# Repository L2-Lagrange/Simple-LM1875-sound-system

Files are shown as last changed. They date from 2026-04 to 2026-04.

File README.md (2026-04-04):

# Simple-LM1875-sound-system
<br>
<p align="center"><strong>Introduction</strong></p>
Below is my design for a simple, modular LM1875 bridge-tied-load (BTL) sound system. It is a practical analog amplifier system that is easy to build, has great performance  and makes for a great analog system design learning project. <br>
<br>
This writeup is meant to offer practical advice for hobbiests and engineers trying to learn more about analog amplifier hardware, and who may be interested in building similar circuits. It is not meant to be an academic document but I do brush on some academic topics. I attempt to focus on the topics I think are important while being as brief as possible.<br>
<br>
The core system is the power amplifier board, but I also provided information on the receiver I used for this version of the build.<br>

<br>

<p align="center">
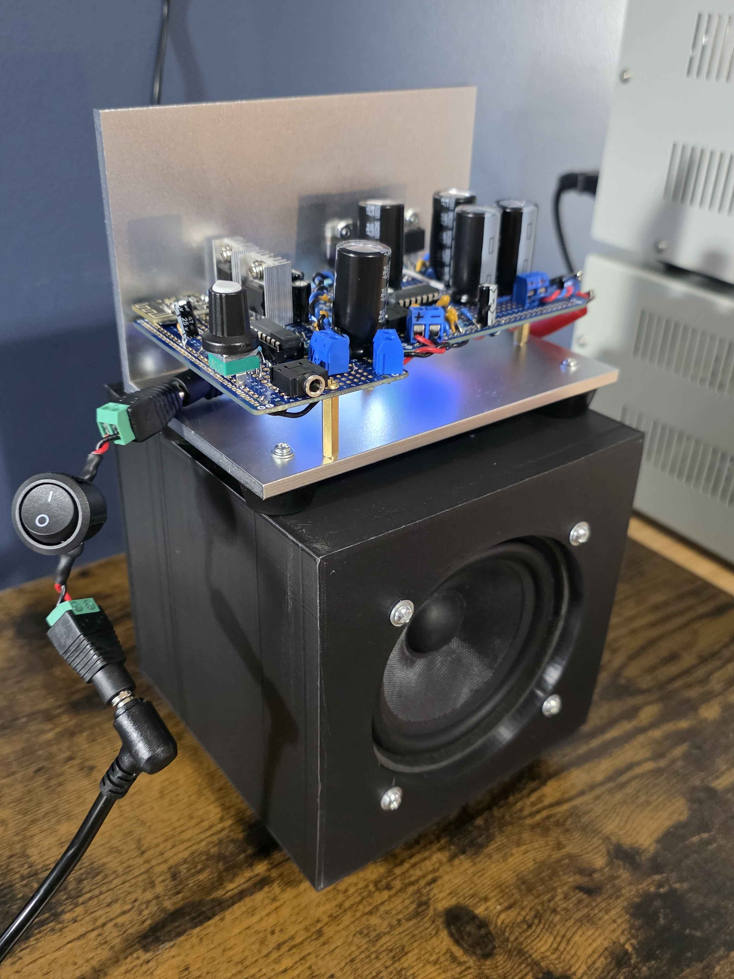
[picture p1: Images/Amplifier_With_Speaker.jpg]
  <br>
  <em>Amplifier system sitting on 3d printed speaker</em>
</p>

<br>
<br>

<p align="center"><strong>The Design:</strong></p>

The system will work with any standard audio signal source, it does not need to be a bluetooth receiver. In this case my signal source is a [$3 bluetooth receiver module from Amazon](https://www.amazon.com/hiBCTR-Wireless-Bluetooth-Audio-Receiver/dp/B0FDLGMMYC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), which is improved with an analog filter stage. You could also use the design as a guitar amplifier or something similar.

<p align="center">
  <br>
  <em> LM1875 amplifier system prototype </em>
</p>

This design is modular and consists of two main boards. One board is a receiver that includes an analog filter for reducing DAC noise, followed by a gain stage and output buffer. The other board is an LM1875 power amplifier board with an input buffer, phase splitter, and bridge-tied-load output. Each subsystem can be built one at a time on breadboard/perfboard and tested before building the next stage. They can also be used as building blocks for other systems.

<p align="center">
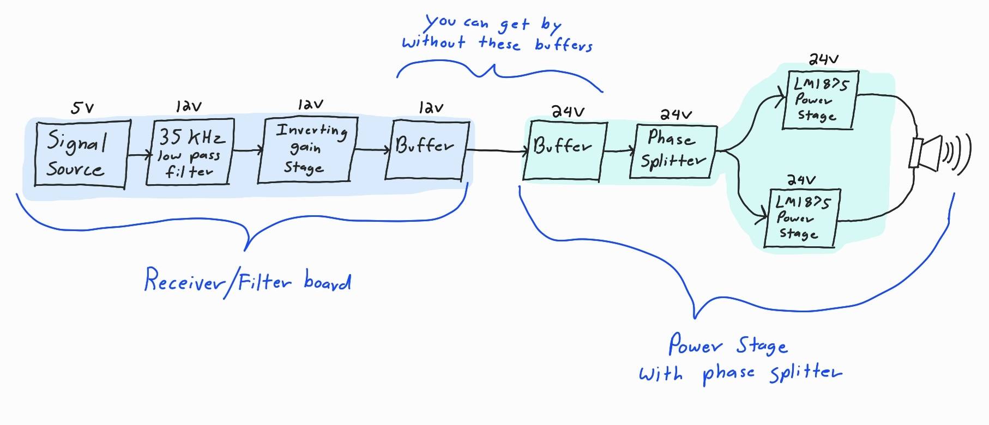
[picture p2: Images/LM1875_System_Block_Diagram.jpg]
  <br>
  <em>System block diagram</em>
</p>
<br>
<br>

<p align="center"><strong>Power Stage:</strong></p>

The LM1875 power stage has a BTL output. This means the output is taken across a pair of amplifiers that have opposite outputs which doubles the voltage. Doubling the voltage increases power output by roughly 4 times compared to a single non BTL LM1875 (schematic below) making it more practical to build loud analog amplifiers at low voltage rails.

<p align="center">
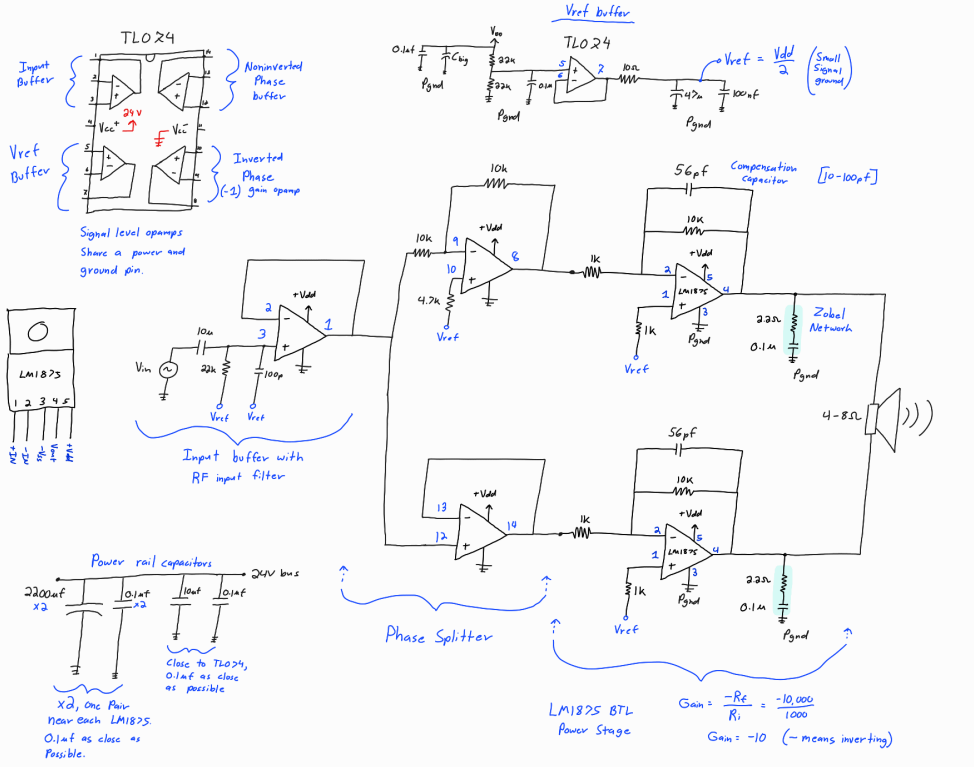
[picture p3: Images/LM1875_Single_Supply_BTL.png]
  <br>
  <em>Schematic:  Power Stage with phase splitter</em>
</p>

To make BTL work, we use a phase splitter. The phase splitter takes in one signal, and outputs the original signal as well as its inverted version. The phase splitter outputs drive the LM1875 power amplifier stage. This design runs from a single DC rail instead of positive and negative rails, so the phase splitter and power stage require a virtual ground. It uses a buffered voltage divider (Vref buffer) to generate and distribute the virtual ground to the TL074 and LM1875 amplifiers. The virtual ground at half the supply voltage is what allows us to run the system with a single +24V rail. 

The power stage is set up as a relatively standard inverting amplifier, but it is not an opamp. The datasheet for the LM1875 recommends designing it with gains of 10 or greater for stability purposes, so the power stage has 10 gain. The vast majority of amplifier chips cannot drive a speaker, which is why we are using the LM1875. The LM1875 is still avalible in standard supply chains.

The power stage includes compensation capacitors in the LM1875 feedback loops (56pf capacitors) as well as zobel network (2.2ohm + 0.1uf) on output. The LM1875 tends to oscillate without a zobel network so it is very important. The feedback capacitors improve square wave response, reducing ringing and indicating good stability. Without them there is noticable ringing on the rising and falling edges.

<p align="center">
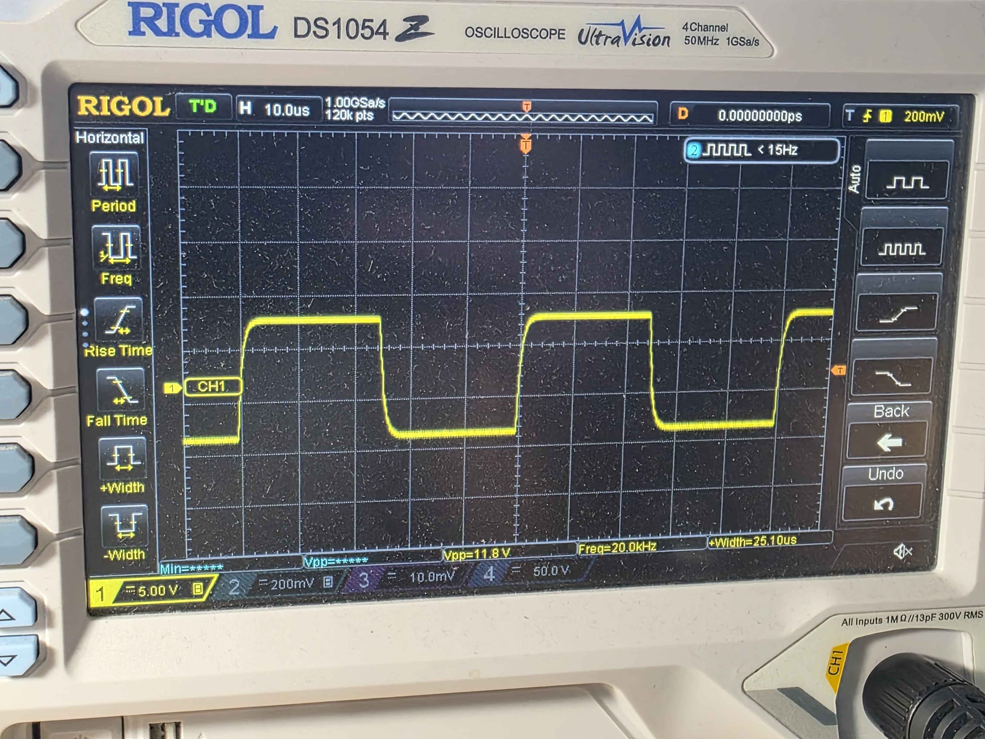
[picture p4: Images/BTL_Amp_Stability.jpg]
  <br>
  <em>Power stage tuned with 56pf capacitor with 8 ohm test load</em>
</p>

<br>
<br>
<p align="center"><strong>Receiver Board:</strong></p>

The receiver board also uses a buffered voltage divider, but its power setup is more complicated due to the addition of the LM7805 and LM7812 voltage regulators. The regulators are separated from the main power bus by a pi filter. This is helpful for cleaning up some noise from cheap wall power supplies. The 7812 regulator is there to power the 12V analog filter section, and the 7805 regulator is used to power the 5V receiver board. (Depending on opamp and receiver choice, this board could be made to run on a single 3.3V rail.)

<p align="center">
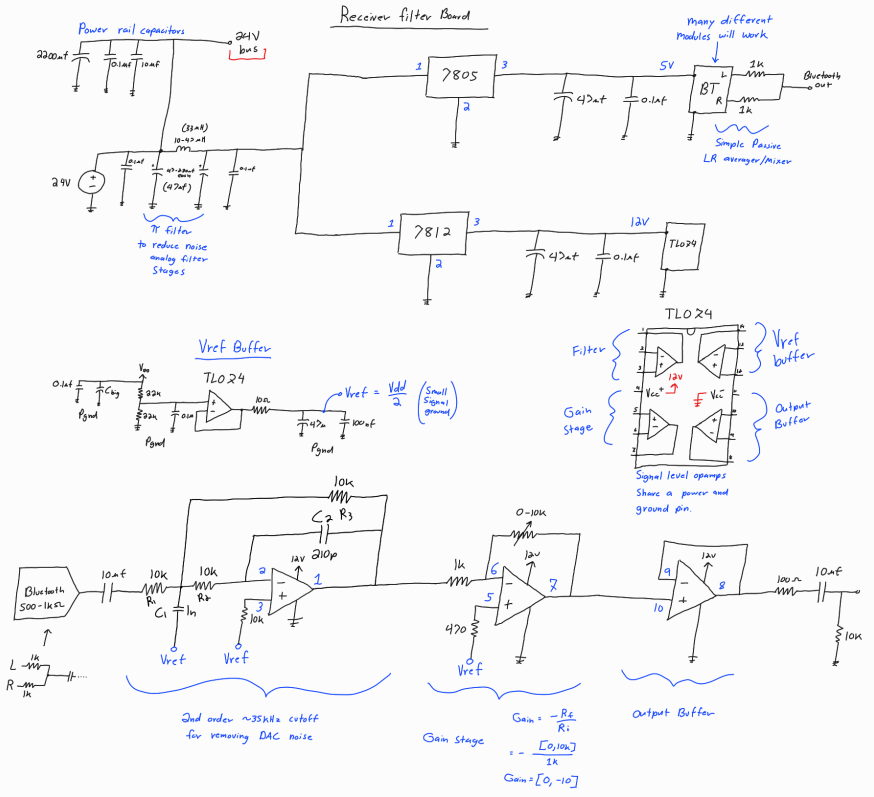
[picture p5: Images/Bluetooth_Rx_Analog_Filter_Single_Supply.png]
  <br>
  <em>Schematic:  Receiver/Filter board</em>
</p>

The most important feature of the receiver board is the 2nd order ~35khz cutoff filter. This is what allows us to use various bluetooth receivers, or arbitrary signal sources. The noise is technically higher than audible frequency, but its good design practice to get rid of it. The 2nd order filter topology originally came from a Texas Instruments design manual, but they have removed it from the internet. I redesigned it for 35khz and this version works well for audio.

<p align="center">
  
  <br>
 <em>Sine wave before (yellow) and after (blue) the 35khz filter</em>
</p>
 
The above images are an example of what the lowpass filter after a DAC accomplishes. The yellow signal is the output from the [bluetooth receiver](https://www.amazon.com/hiBCTR-Wireless-Bluetooth-Audio-Receiver/dp/B0FDLGMMYC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), and the blue signal is the output of the 35khz filter. The high frequency noise has been significantly removed, and the output is much cleaner. This sine wave is then reinverted by the gain stage (0-10 gain magnitude) and then finally sent to the output buffer. 

The signal then goes to the input stage of the power stage board, which is another buffer. These buffers are for modularity and stage separation, but they could be removed. After the buffer the signal is phase split to drive the BTL power stage.

<br>
<br>
<p align="center"><strong>Output Power Measurements:</strong></p>

The power stage measurements are taken 'single ended,' which means the measurement are taken from one amplifier output to ground as opposed to taking the output across the load. This is because the bridge-tied-load is floating with respect to ground. To interpret the measurements, you would double the voltage across the load (the output is differential). You could also measure both channels and add them using an oscilloscope math function. 

The power calculations get a little bit complicated due to the BTL changing 'how the amplifier sees the load.' This configuration makes each amplifier half bridge 'see' half the resistance of the load, so it 'sees' 4 ohms when connected to an 8 ohm load. 

<p align="center">
  
  <br>
 <em>Left: Test setup,    Right: Max power into 8 ohms before clipping</em>
</p>

The maximum output voltage before clipping is roughly 14.6V pk-pk per channel. This means the voltage across the load would be 29.2V pk-pk (10.36Vrms). At this point we can use (V^2)/R to estimate a power output of 13.42W before noticeable distortion. This is significantly louder than you would expect. It can operate into clipping and still sound good. The power output is similar into a 4 ohm load, but it has less voltage headroom before clipping and significantly higher current. 

<p align="center">
  
  <br>
 <em>Left: Onset of clipping with 8 ohm load,   Right: Clipping with 8 ohm load</em>
</p>

As the system approaches clipping, it gets a little bit of fuzz on top of the sine wave before flattening out with increasing input amplitude. When listening to music the bass tends to clip a tiny bit first and its not audible. 
<br>
<br>
<p align="center"><strong>LEDs:</strong></p>

I included three LEDs on the power rails. I would recommend adding at least one to each board. They indicate whether or not the circuit is on and the capacitors are charged. It also gives the capacitors a discharge path when the circuit is powered off. I chose to use a 3rd LED for visual reasons.

<p align="center">
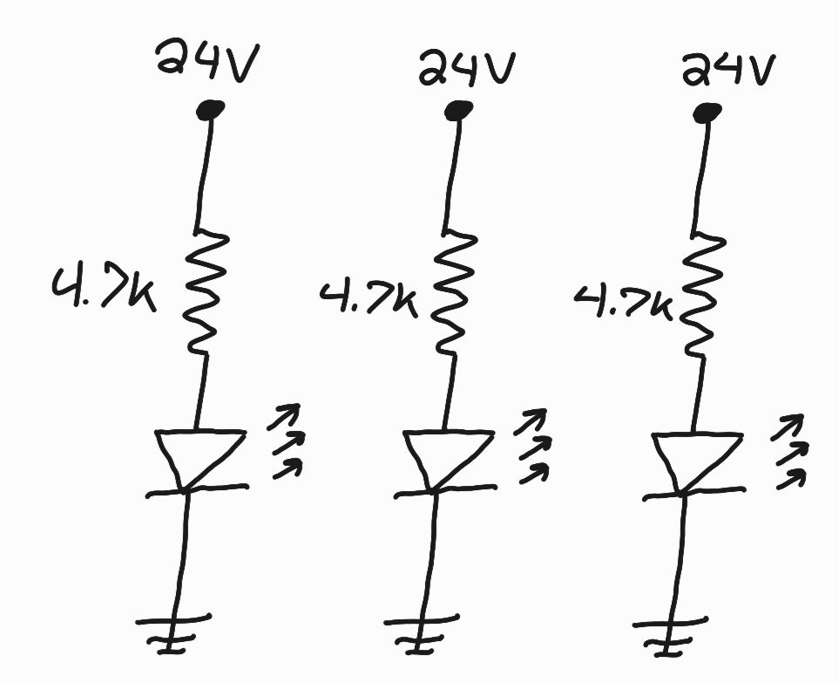
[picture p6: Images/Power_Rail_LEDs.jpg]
  
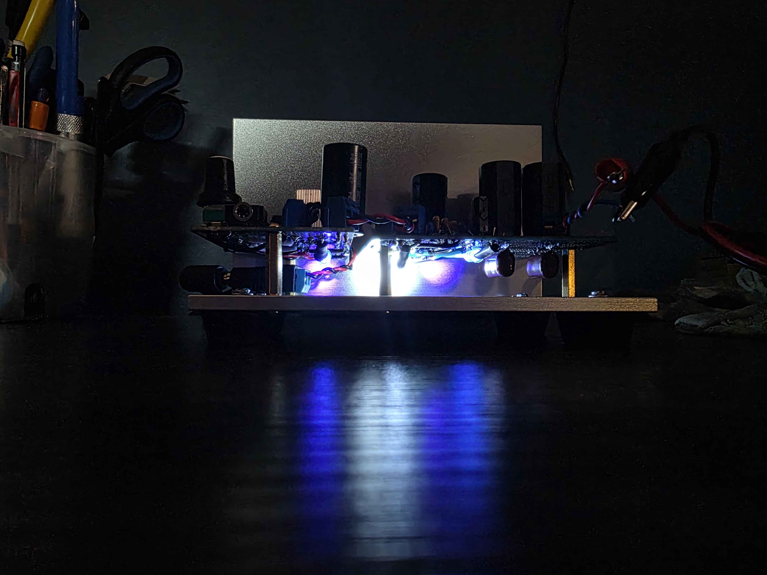
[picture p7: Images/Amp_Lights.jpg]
  <br>
 <em>Power rail LEDs</em>
</p>

<br>
<br>
<p align="center"><strong>Heat Sink:</strong></p>

Proper heat sinking is important for the power stage. For the heat sink I used an [aluminum L bar](https://www.amazon.com/OTTFF-Bracket-aluminum-Profile-Corner/dp/B0DD3BDWT6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) which gave me space to mount both boards on standoffs, but you can get by with [significantly smaller heat sinks](https://www.amazon.com/dp/B07B62V4FP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). You will not be able to test the system at full power with the smaller heat sinks, but it will get plenty loud. 

I placed my prototype on the aluminum L bar and used a sharpie to mark where I needed to drill. I used cheap drill bits appropriate for aluminum and added a little bit of vegetable oil to the drill hole (the vegetable oil makes a big difference). This worked very well. A small amount of thermal paste significantly improves the thermal transfer from the LM1875 chips to the heat sink.

<p align="center">
  
  <br>
 <em>Left: Power stage on heat sink ,   Right: Drilling the heat sink</em>
</p>

Once a heat sink is drilled the LM1875 chips can be connected to it. Make sure to plan your builds to include the heat sink from the start. It is very difficult to properly heat sink chips that are populated in the center of boards, and you do not want your system to be completely limited by heat sink performance.

<br>
<br>
<p align="center"><strong>LM1875 Single Supply Inverting Amplifier (not BTL):</strong></p>

When building this system for the first time it helps to build a simple version of the power stage. The design below is an LM1875 inverting power stage I designed. The output capacitor is very important in this design, but it should be removed for BTL.
<br>
<p align="center">
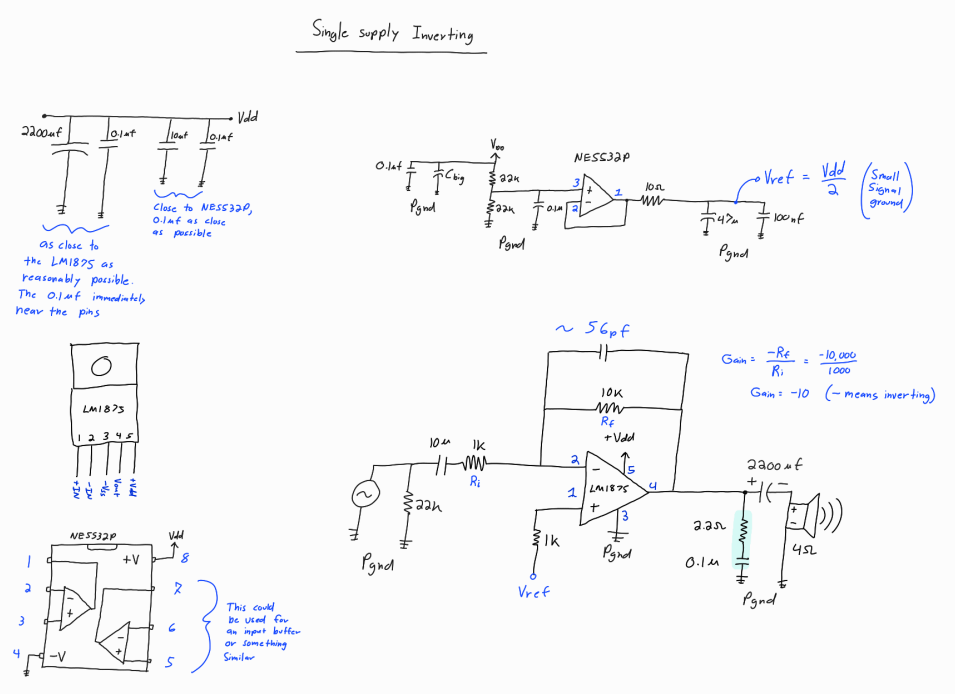
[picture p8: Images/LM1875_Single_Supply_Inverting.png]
  <br>
  <em>LM1875 non BTL inverting power amplifier</em>
</p>

This can easily be tuned on a breadboard. I've also built three soldered versions to use in my [LR4 active system](https://www.linkwitzlab.com/filters.htm) design. It has great performance on its own, but significantly better power performance as a BTL. The feedback capacitor can be tuned while measuring a 10khz square wave and looking at the edges. I tuned it by swapping out capacitor values and taking measurements. Below is an image of the properly tuned LM1875 power stage square wave. Notice the lack of ringing on the edges.

<p align="center">
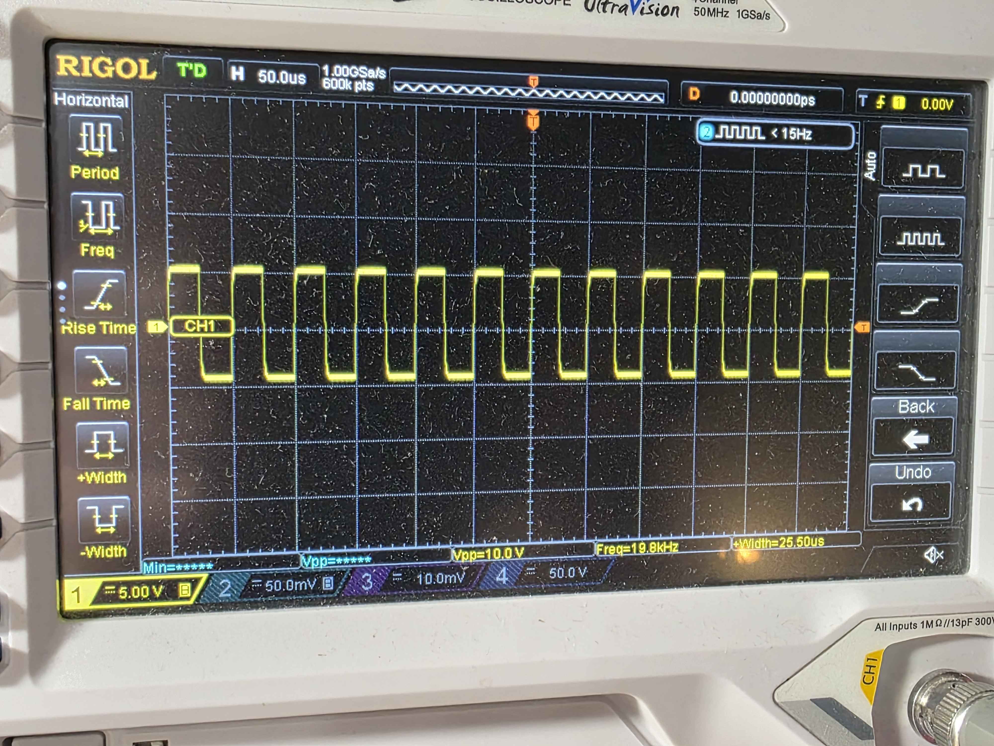
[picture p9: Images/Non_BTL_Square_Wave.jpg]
  <br>
  <em>Stable square wave resulting from proper compensation</em>
</p>

<br>
<br>
<p align="center"><strong>Conclusion:</strong></p>

The performance of the system is better than I expected, so I decided to explain how it works and provide advice for building something similar. The analog part of the reciever board and LM1875 BTL power board are both great building blocks for larger systems. That being said I have spent more time testing systems built from the non BTL inverting version and that is a great starting place. Almost every component could be swapped out for a similar component within specification. For example the TL074 and NE5532P circuits could use higher quality modern amplifiers, but that is not worth it unless you have a very high quality signal source. Even then the NE5532P is a perfectly fine hifi part. There is a lot of wiggle room in the design in general. Just make sure to check the voltage ratings on the components you choose so they will actually work in the design. 

The system is designed to work with a somewhat wide input supply voltage. One of the major advantages of using off the shelf power supplies is being able to take advantage of the built in protectoin circuitry. If you design your own power supply it is important to include sufficient protection circuitry. 

Below are various loosely related bits of information that didnt fit cleanly into a previous sections. It includes practical information from my eperience working with this design.

<br>

<br>
<br>
<p align="center"><strong>Build Notes:</strong></p>

1. The semiconductors and electrolytic capacitors for this project were ordered from Digikey. The LM1875 chips are the most important component to get from a reliable source. Do not buy them on Amazon. 

2. The system is powered by a single DC voltage source between 18-30V, and performs great with [cheap 24V wall power supply bricks](https://www.amazon.com/100V-240V-Terminal-Connector-Adapter-5-5x2-1mm/dp/B0CW598HV8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). This means you do not need to build a power supply to design a similar system. That being said a well designed 24V linear power supply using an LM317HV would be a good choice.

3. The speaker below the amplifier is 3D printed, but this system should work with any speaker rated at least 30W. This particular build uses a single [PRV Audio 4 inch midrange 30W RMS speaker](https://www.amazon.com/PRV-4MR60-4-Midrange-Woofer-Speaker/dp/B00RC3Z9H2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), but I have tested it with many other 4 and 8 ohm speakers. This document focuses on the power amplifier and bluetooth receiver boards.

4. The bluetooth receiver used in this particular build [costs roughly $3 on Amazon.](https://www.amazon.com/hiBCTR-Wireless-Bluetooth-Audio-Receiver/dp/B0FDLGMMYC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) This receiver works great and uses incredibly low power, but there are more hifi options. There are also no official datasheets available for the chip, but it is still easy to work with. The analog filter after the bluetooth receiver significantly improves the signal quality and makes it usable in a system like this.

5. The power rails include bulk electrolytic capacitors and small ceramic capacitors. It is important to have at least a few thousand uF of capacitance on the power rails for the LM1875 board. It is also important to keep 0.1uf ceramic capacitors immediately near each chip's power pins. I tend to add a 0.1uf capacitor in parallel next to each bulk cap, and then a few extras around the board for good measure. There is a lot of wiggle room for capacitance on the rails. For the capacitor voltage rating, use a value that is around 50% higher than your power rail. For a 24V rail you want to use at least 35V rated capacitors. I used 50V rated capacitors in my build.

6. Dropping 24V to 5V on a linear regulator is a lot, and the rail draws more than ~15-20mA of current it will get extremely hot. You may need a buck converter instead of linear regulator depending on the receiver, or you could use a receiver on a completely different board. Buck converters are noisier than linear power supplies, but they are significantly more efficient. I do not recommend using an LM2596 but it could work in a pinch.

7. The receiver is interchangeable, and the system would greatly benefit from a higher quality receiver. One can be made pretty easily with an ESP32 devboard and PCM5102 module with the filter stage, or you can use a professional bluetooth receiver. Depending on what receiver you use, you can get by without the filter board entirely.

8. The receiver board could be used with any other amplifier system, but you may want to re-design the voltage rails so you arent stuck with the 24->5V linear regulator voltage drop.

9. The STL files for the printer enclosure are avalible the folder "3D-STL-Files." It is not the best design but it works well with the [PRV Audio 4 inch midrange 30W RMS speaker](https://www.amazon.com/PRV-4MR60-4-Midrange-Woofer-Speaker/dp/B00RC3Z9H2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). The sound quality greatly benifits from polyfill and speaker baffle tape. A wood enclosure would work way better.

10. It would be a good idea to add a fuse to the power input. Having power protection circuitry becomes incredibly important if you design your own power supply. One major advantage of using random wall ~24V wall power supplies is the ability to take advantage of the built in protection circuitry.

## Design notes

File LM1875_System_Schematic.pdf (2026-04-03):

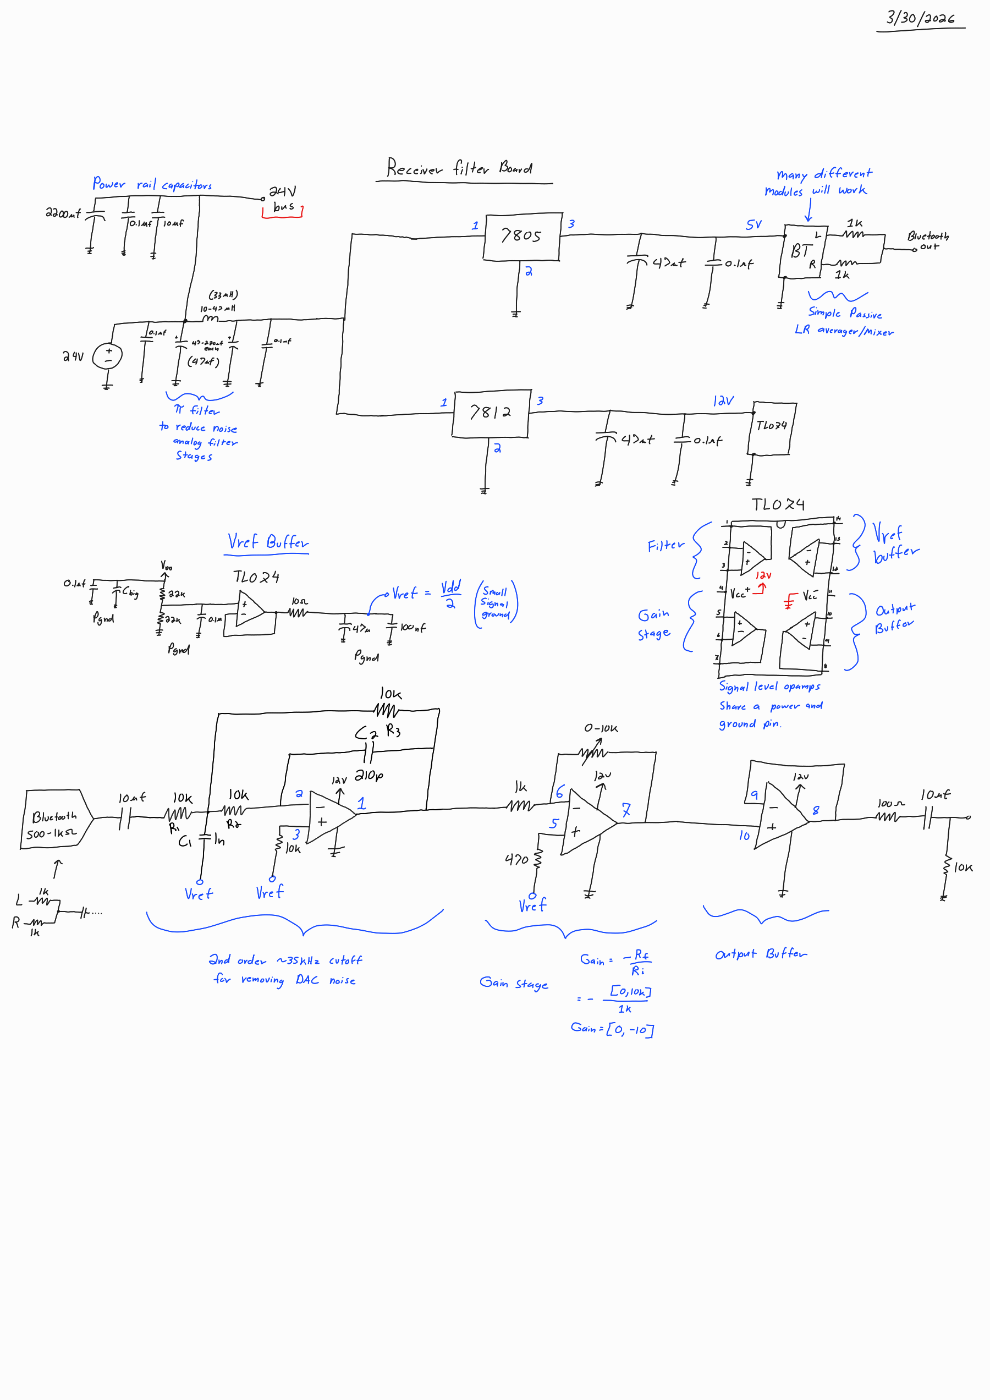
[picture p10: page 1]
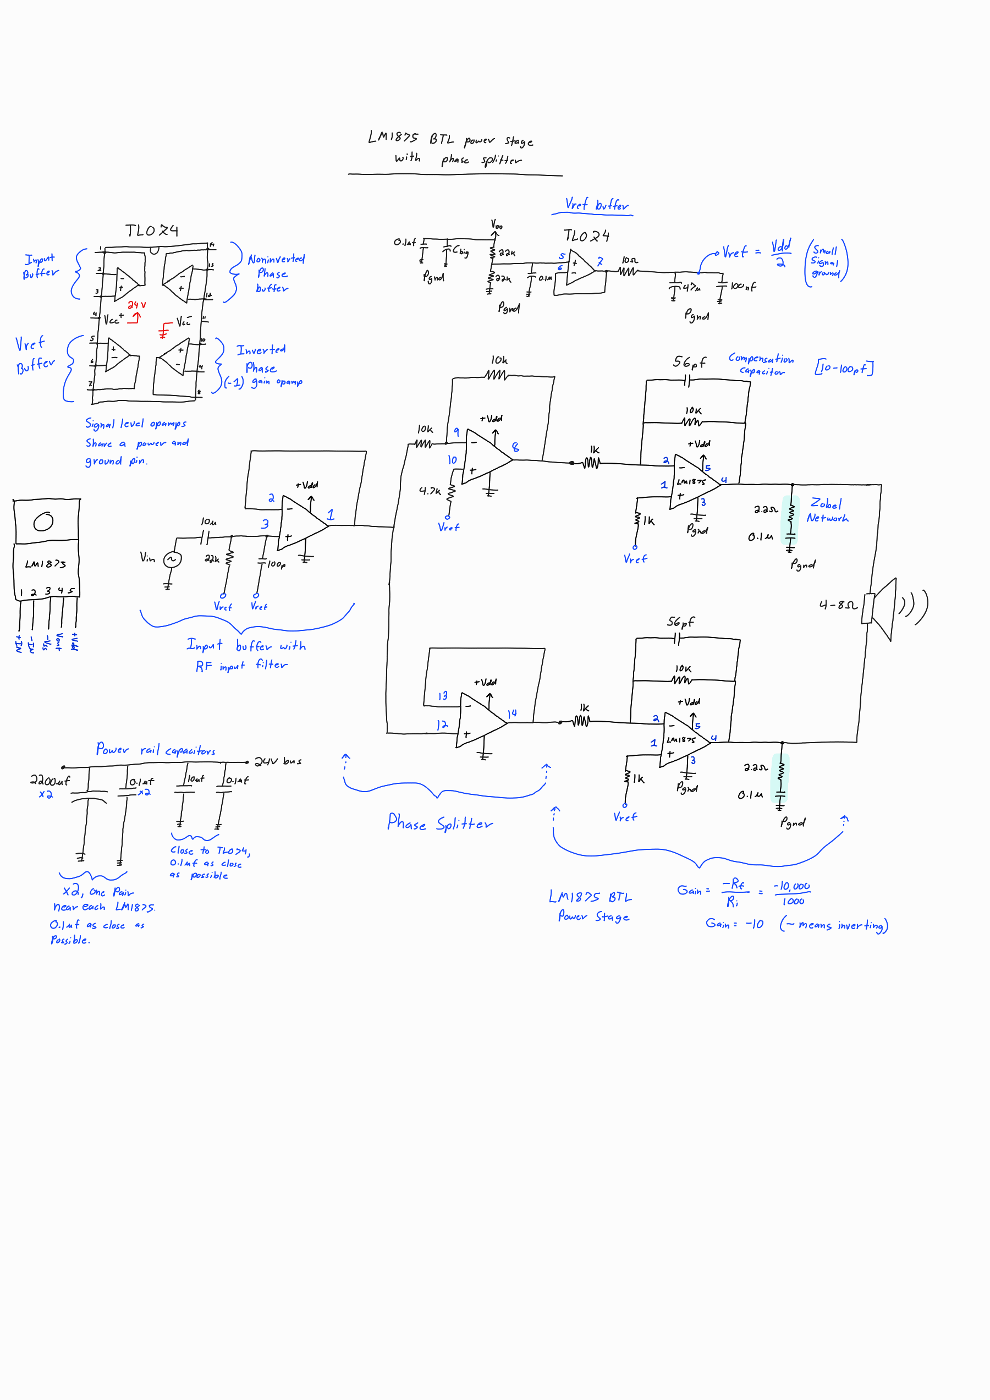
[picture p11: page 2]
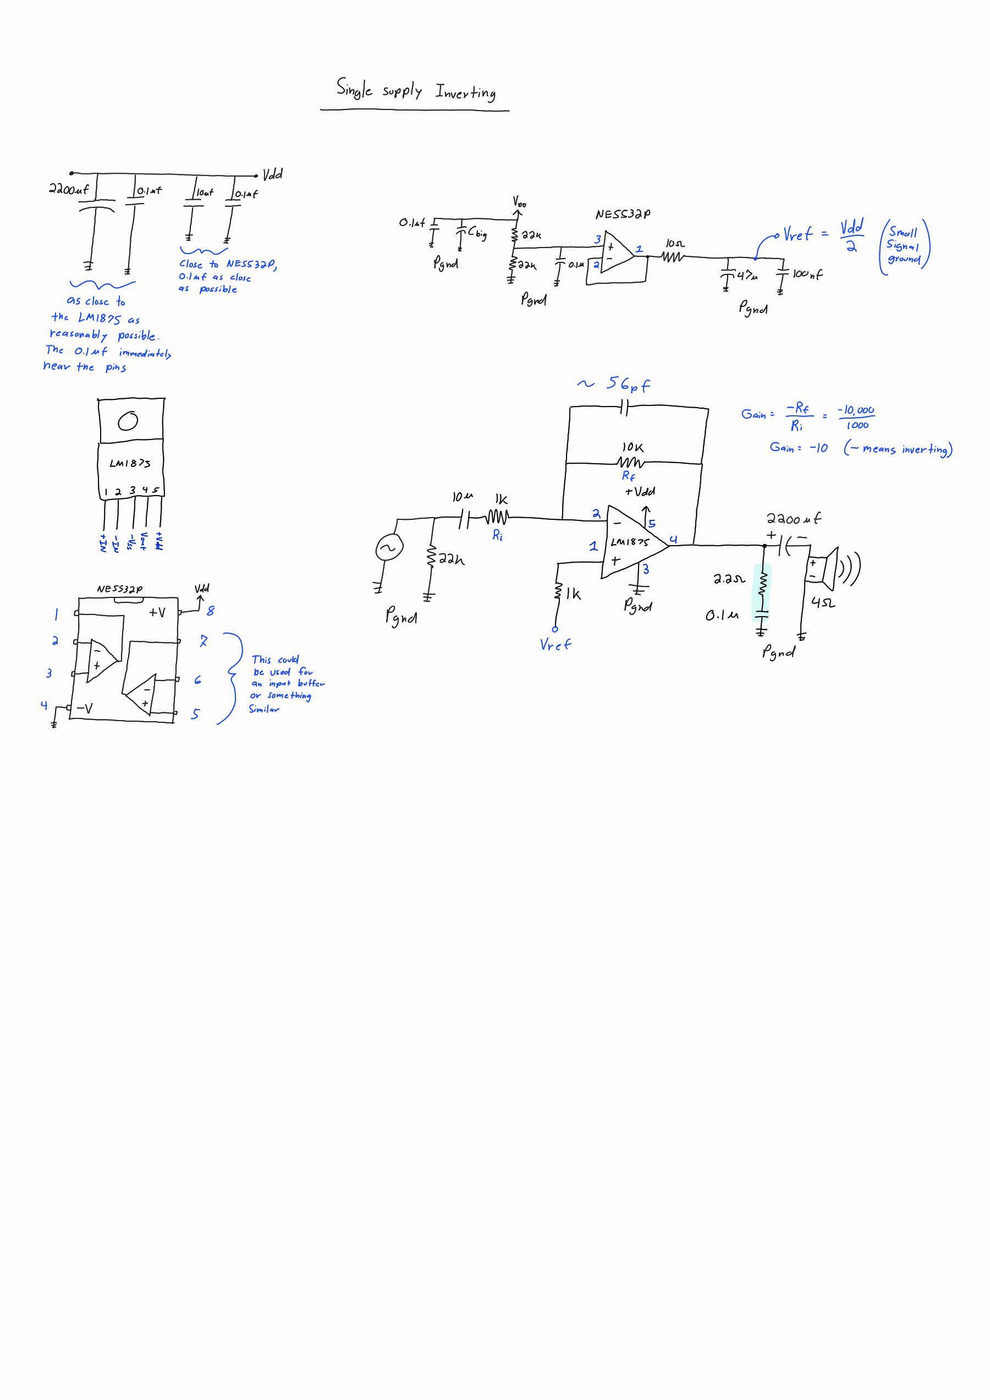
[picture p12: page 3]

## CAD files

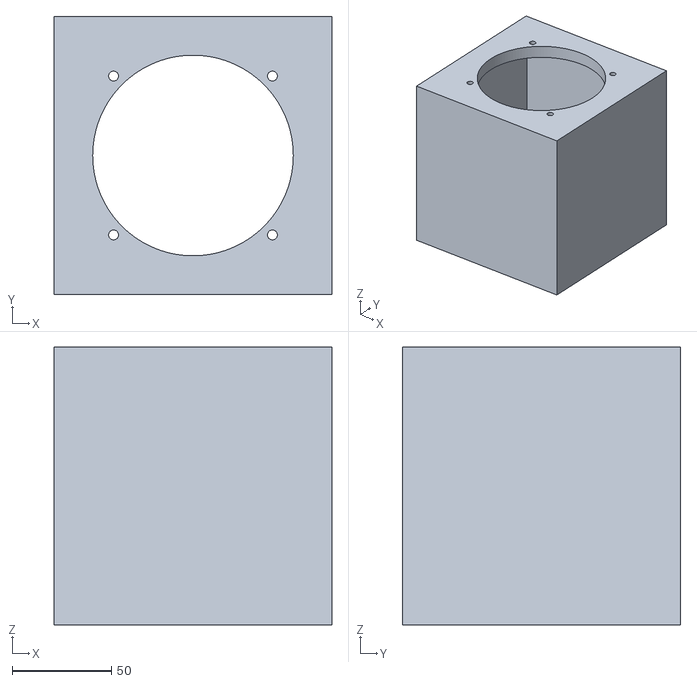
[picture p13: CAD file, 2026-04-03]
3D-STL-Files/4Inch_Speaker_Box_V1.stl
140.0 x 140.0 x 140.0

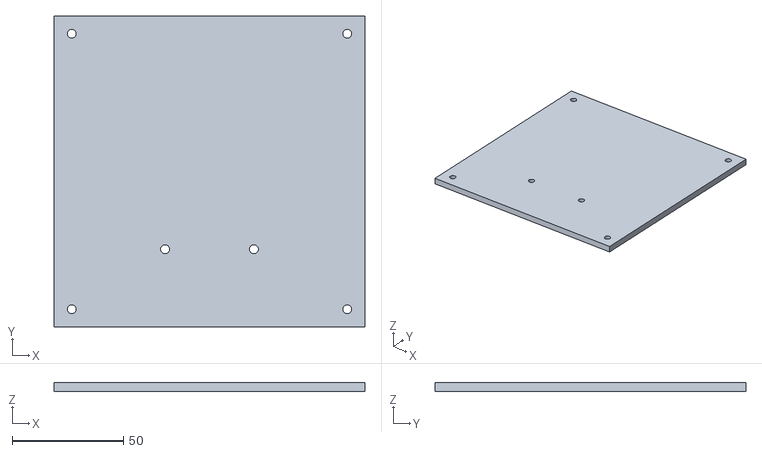
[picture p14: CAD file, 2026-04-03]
3D-STL-Files/Back_Plane-Body001.stl
140.0 x 140.0 x 4.00

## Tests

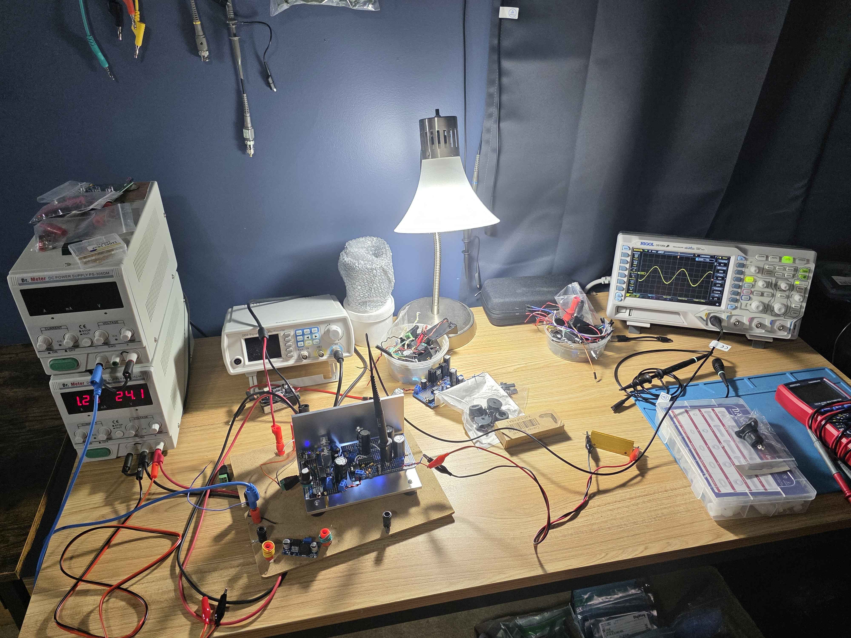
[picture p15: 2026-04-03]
Images/AmpTestSetup.jpg
